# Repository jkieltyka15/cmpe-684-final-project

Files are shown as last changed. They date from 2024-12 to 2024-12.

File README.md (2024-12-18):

# Smart Wireless Sensor Network (WSN) Parking Lot
## Overview
This repository is a collection of research, hardware implementations and software implementations for a smart parking lot that displays the vacancy status of each parking space. The scope of the project was limitted to ten spaces and is meant to be a proof of concept to satisfy the final project requirement for CMPE-684: Wireless Sensor Networks at the University of Maryland, Baltimore County.

## Hardware
All PCB design files were created using KiCad and all stl files for 3D prints were developed using Autodesk TinyCAD. The filament used for the 3D prints is PLA.

For electronics, the project truly revolves around the Arduino Nano. All of the sensor nodes and the base station utilize this microcontroller. Time of Flight (ToF) sensors are used to detect if a vehicle is present and the NRF24L01 radio is used for network communication between sensor nodes and the base station.

The output of the base station is composite video with a limitted display resolution. However, the final resolution seems to scale well with most display scalers.

## Software
The Arduino IDE was used for the research examples. However, PlatformIO was used for the actual implementation since it offered superior project structure and organization.

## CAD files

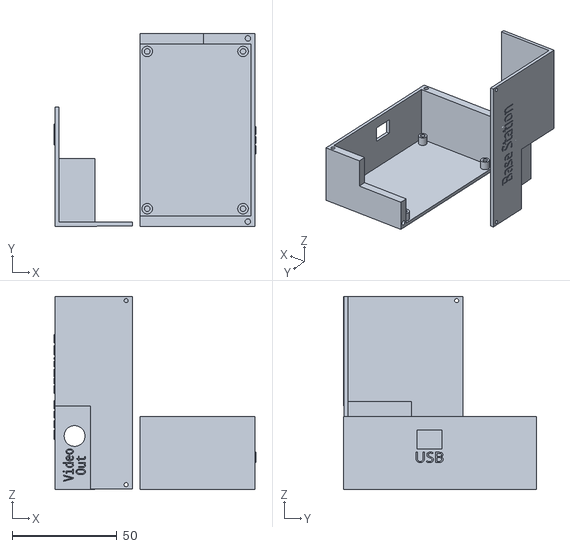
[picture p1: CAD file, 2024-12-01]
base_station/3d_print/base_station.stl
96.5 x 92.3 x 92.3

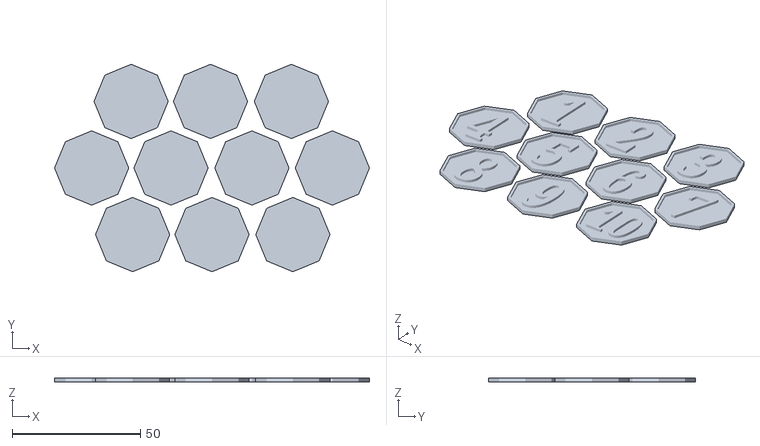
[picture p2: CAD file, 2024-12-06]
sensor_node/3d_print/number_tags.stl
123.0 x 81.0 x 1.50

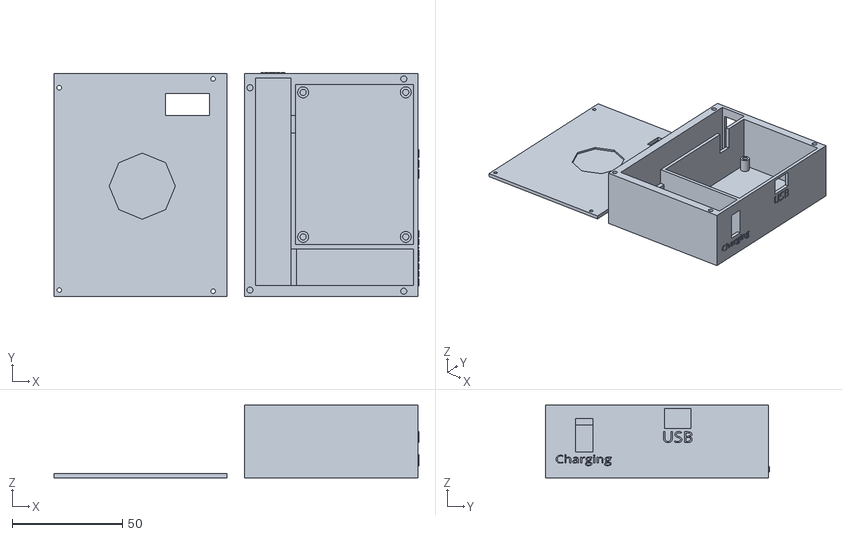
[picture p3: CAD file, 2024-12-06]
sensor_node/3d_print/sensor_node.stl
165.4 x 101.5 x 33.0

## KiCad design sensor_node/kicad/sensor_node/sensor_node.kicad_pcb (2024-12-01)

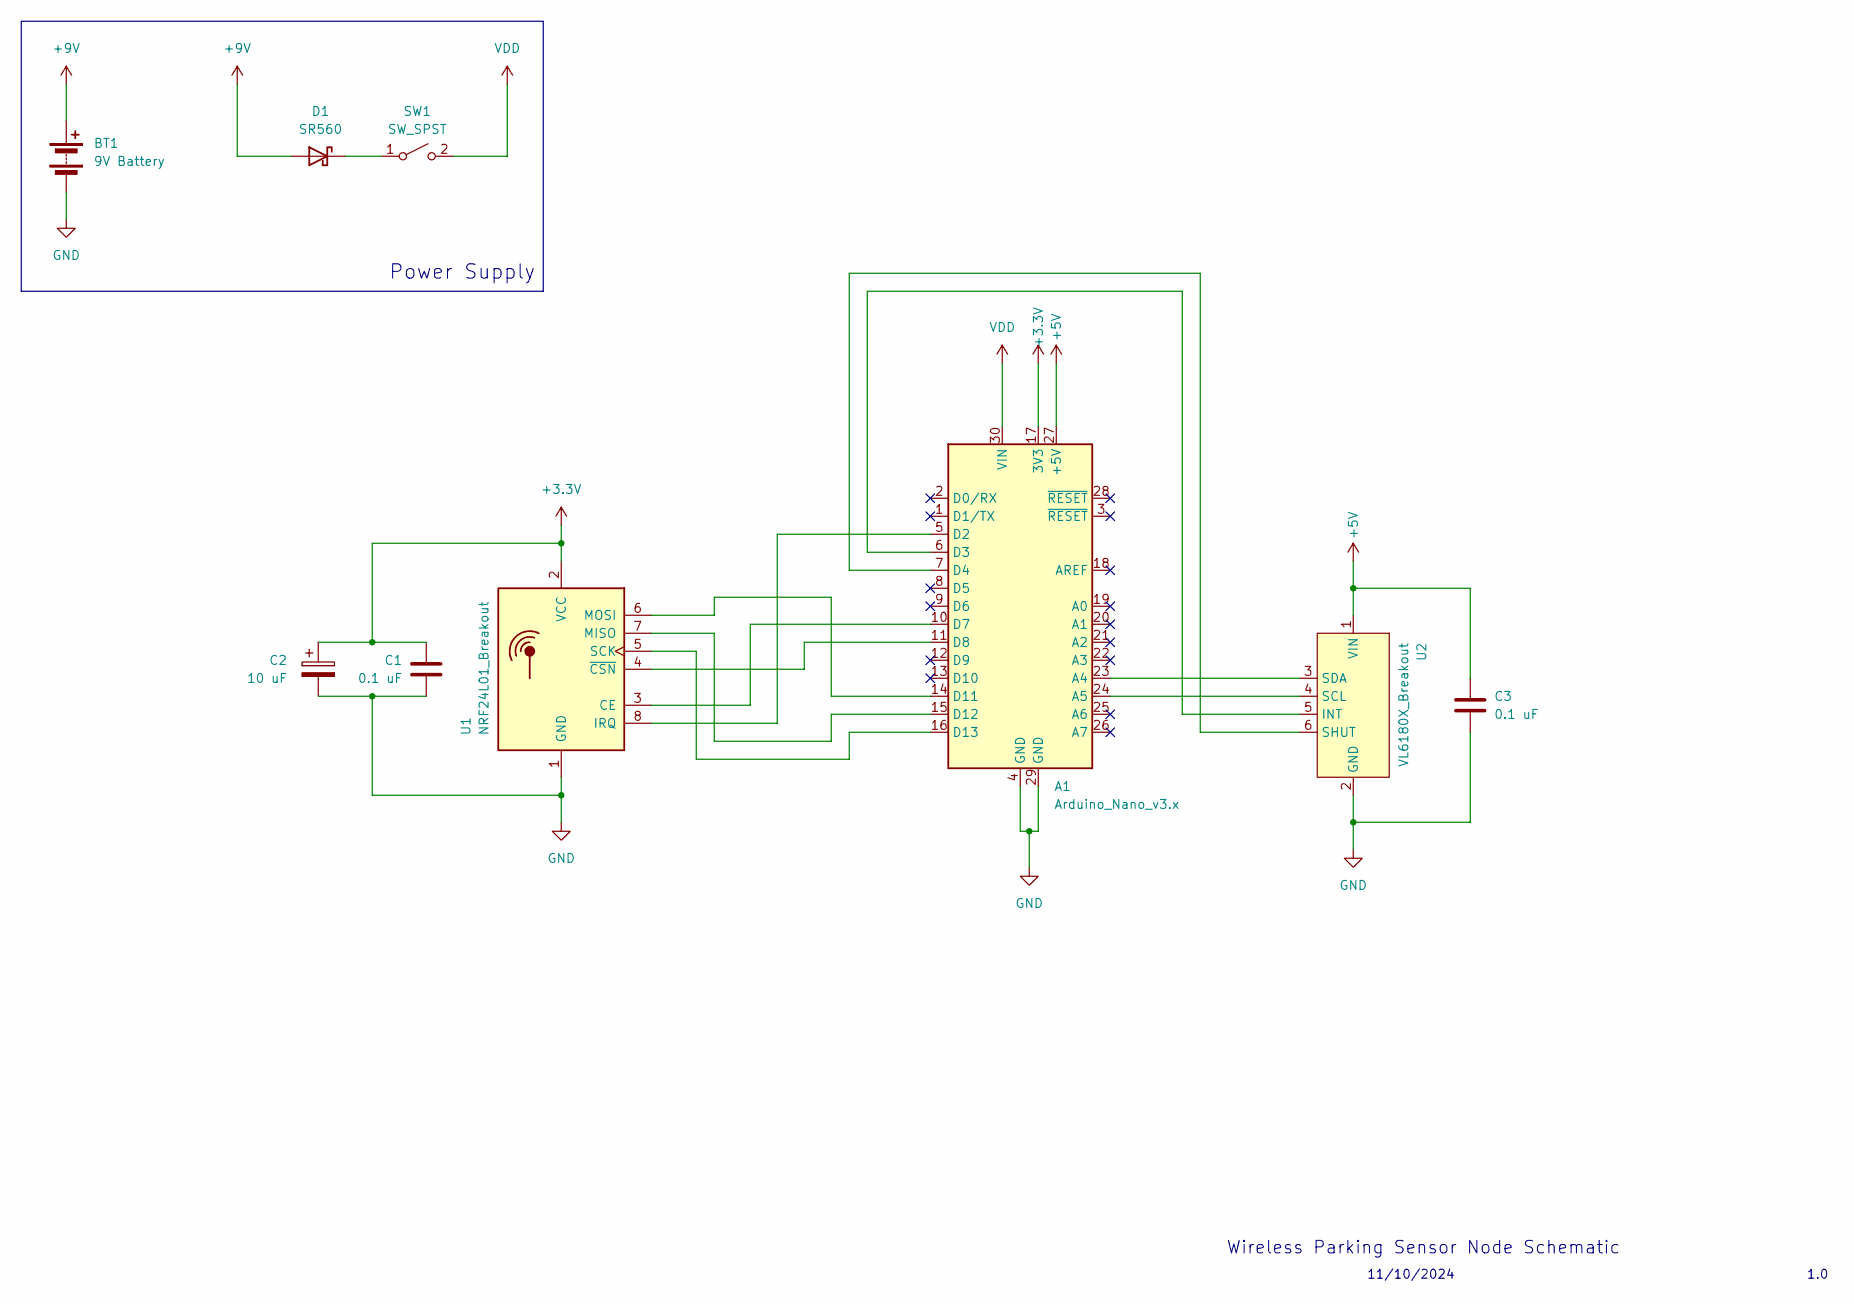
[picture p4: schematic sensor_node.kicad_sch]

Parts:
A1: Arduino_Nano_v3.x; Arduino_Nano
BT1: 9V Battery; PinHeader_1x02_P2.54mm_Vertical
C1, C3: 0.1 uF; C_Disc_D5.1mm_W3.2mm_P5.00mm
C2: 10 uF; CP_Radial_D5.0mm_P2.50mm
D1: SR560; D_DO-201AD_P15.24mm_Horizontal
SW1: SW_SPST; PinHeader_1x02_P2.54mm_Vertical
U1: NRF24L01_Breakout; nRF24L01_Breakout
U2: VL6180X_Breakout

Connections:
+3.3V: A1.17 (3V3), C1.1, C2.1, U1.2 (VCC)
+5V: A1.27 (+5V), C3.1, U2.1 (VIN)
+9V: BT1.1 (+), D1.2 (A)
GND: A1.4 (GND), A1.29 (GND), BT1.2 (-), C1.2, C2.2, C3.2, U1.1 (GND), U2.2 (GND)
unnamed: A1.23 (A4), U2.3 (SDA)
unnamed: A1.24 (A5), U2.4 (SCL)
unnamed: A1.5 (D2), U1.8 (IRQ)
unnamed: A1.6 (D3), U2.5 (INT)
unnamed: A1.7 (D4), U2.6 (SHUT)
unnamed: A1.10 (D7), U1.3 (CE)
unnamed: A1.11 (D8), U1.4 (~CSN)
unnamed: A1.14 (D11), U1.6 (MOSI)
unnamed: A1.15 (D12), U1.7 (MISO)
unnamed: A1.16 (D13), U1.5 (SCK)
unnamed: D1.1 (K), SW1.1 (A)
VDD: A1.30 (VIN), SW1.2 (B)

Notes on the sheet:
11/10/2024
1.0
Wireless Parking Sensor Node Schematic
Power Supply

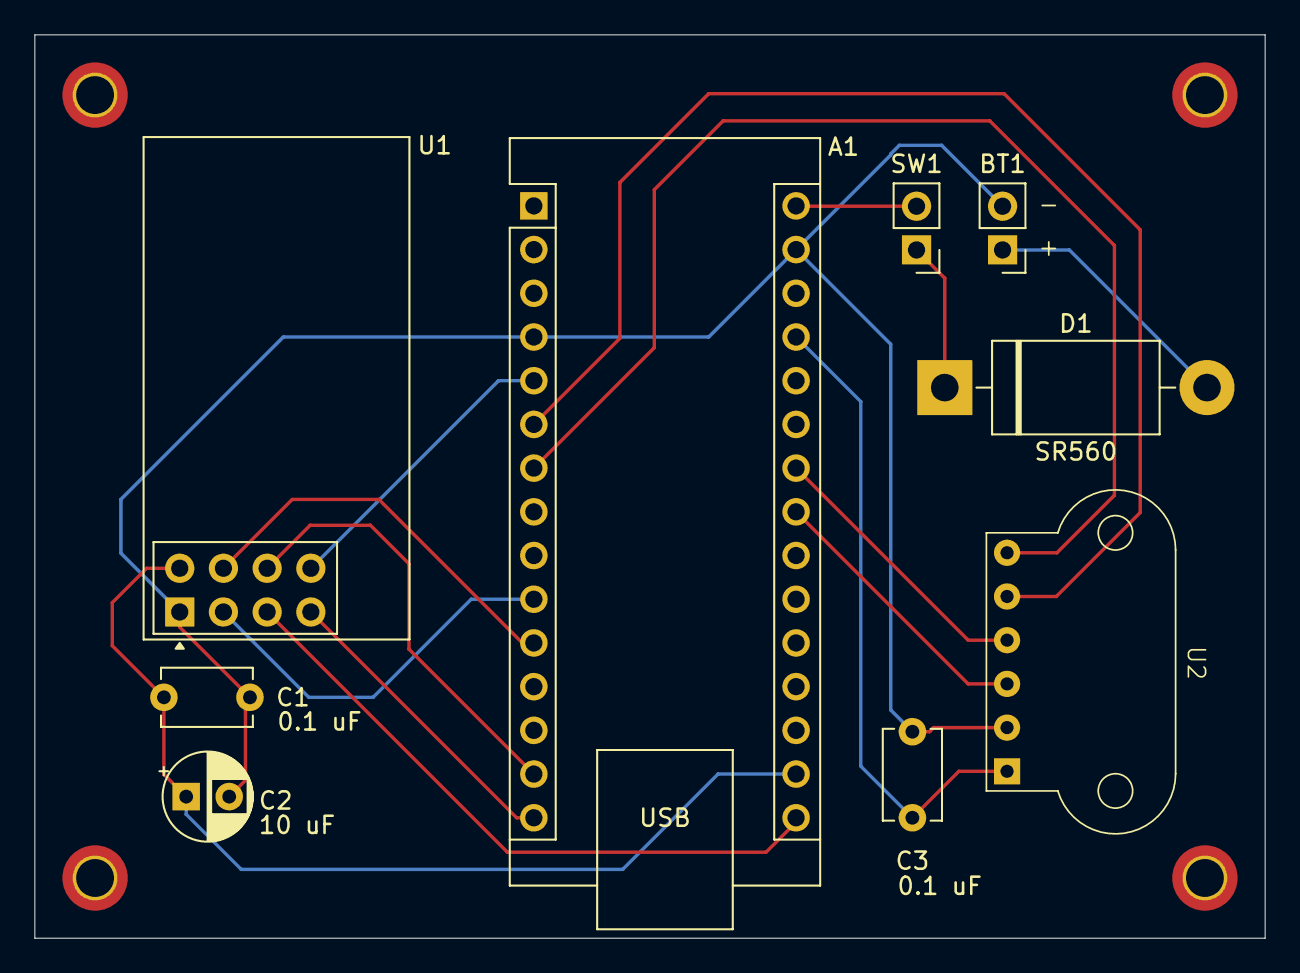
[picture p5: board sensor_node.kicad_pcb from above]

Board: 2 copper layers, 71.5 x 52.5 mm, 13 parts (0 on the bottom side), 16 nets.

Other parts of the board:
MH1, MH2, MH3, MH4: MountingHole_2.2mm_M2_DIN965_Pad_TopBottom

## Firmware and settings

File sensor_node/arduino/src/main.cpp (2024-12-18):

/**
* @brief: Contains the main run loop for the parking sensor node.
* @file: main.cpp
*
* @author: jkieltyka15
*/

// standard libraries
#include <Arduino.h>
#include <stdlib.h>
#include <Wire.h>
#include <Adafruit_VL6180X.h>

// local libraries
#include <Log.h>

// local dependencies
#include "sensornode.hpp"
#include "parkingmap.hpp"


// unique ID for node
#define NODE_ID 10

// baud rate for serial connection
#define SERIAL_BAUD 9600


#define MAIN_LOOP_DELAY_MIN_MS 75   // minimum delay in main loop in milliseconds
#define MAIN_LOOP_DELAY_MAX_MS 150  // maximum delay in main loop in milliseconds

// number of loop iterations without transmitting a message
// before sending out a heartbeat
#define LOOPS_BEFORE_HEARTBEAT 25

// size of message buffer
#define MSG_BUFFER_SIZE 32


// parking sensor node
SensorNode node = SensorNode(NODE_ID);

// counter for tracking loop iterations since the last
// message was transmitted
uint8_t loops_since_last_transmission = 0;

/**
 * @brief Initialize all necessary objects and variables.
 */
void setup() {

    Serial.begin(SERIAL_BAUD);
  
    // initialize the sensor node
    if (false == node.init()) {

        ERROR("Failed to initialize sensor node. Check hardware")

        // hang since failure is not recoverable
        while(1);
    }

    INFO("setup complete")
}


/**
 * @brief Main program run loop.
 * 
 * Continuously monitors the status of a parking space and sends a message if
 * it changes or the status is requested. Additionally, relays messages from
 * other nodes.
 */
void loop() {

    // track iterations since last transmission
    loops_since_last_transmission++;

    // determine if parking space status has changed or time for heartbeat
    if ((true == node.is_sensor_status_changed())
        || LOOPS_BEFORE_HEARTBEAT <= loops_since_last_transmission) {

        // determine recepient
        int16_t rx_id = get_next_ingress_node(node.get_id());

        // no recepient available
        if (0 > rx_id) {
            WARN("Nobody to send update to")
        }

        else {
            // transmit update
            if (false == node.transmit_update((uint8_t)rx_id)) {
                ERROR("Failed to transmit update message to Node " + rx_id)
            }

            // heartbeat message successfully sent
            else if (LOOPS_BEFORE_HEARTBEAT <= loops_since_last_transmission) {
                INFO("heartbeat update message sent to Node " + + rx_id)
            }

            // update message successfully sent
            else {
                INFO("update message sent to Node " + + rx_id)
            }

            // reset heartbeat iteration counter
            loops_since_last_transmission = 0;
        }
    }

    // check if a message has been received
    else if(true == node.is_message()) {

        uint8_t buffer[MSG_BUFFER_SIZE];
        memset(buffer, 0, sizeof(buffer));

        if (false == node.read_message((uint8_t**)(&buffer), (uint8_t)sizeof(buffer))) {
            ERROR("Failed to read message");
        }

        else {
            // convert buffer to Message
            Message msg = Message();
            memcpy(&msg, buffer, sizeof(msg));

            // verify message is for node
            if (node.get_id() != msg.get_rx_id()) {
                WARN("Message intended for Node " + msg.get_rx_id() + " not Node " + node.get_id());
            }

            // react accordingly based on message type
            else {

                uint8_t type = msg.get_type();
                switch(type) {

                    case MESSAGE_UPDATE: {

                        INFO("Received UPDATE message from Node " + msg.get_tx_id())
                        
                        // convert buffer to UpdateMessage
                        UpdateMessage update_msg = UpdateMessage();
                        memcpy(&update_msg, buffer, sizeof(update_msg));

                        // determine recepient
                        int16_t rx_id = get_next_ingress_node(node.get_id());

                        // no recepient available
                        if (0 > rx_id) {
                            WARN("Nobody to send update to")
                        }

                        else {
                            // create new message to forward
                            uint8_t tx_id = node.get_id();
                            uint8_t node_id = update_msg.get_node_id();
                            bool is_vacant = update_msg.get_is_vacant();
                            UpdateMessage new_msg = UpdateMessage(rx_id, tx_id, node_id, is_vacant);

                            // forward the message
                            if (false == node.transmit_update(&new_msg)) {
                                ERROR("Failed to transmit update message to " + rx_id)
                            }

                            // reset heartbeat iteration counter
                            loops_since_last_transmission = 0;
                        }

                        break;
                    }

                    default:
                        WARN("Unknown message type received")
                        break;
                }
            }
        }
    }

    // nothing to do
    else {
        delay(random(MAIN_LOOP_DELAY_MIN_MS, MAIN_LOOP_DELAY_MAX_MS));
    }
}

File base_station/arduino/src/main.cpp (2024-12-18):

/**
* @brief: Contains the main run loop for the parking lot base station.
* @file: main.cpp
*
* @author: jkieltyka15
*/

// standard libraries
#include <Arduino.h>
#include <stdlib.h>
#include <Wire.h>

// local libraries
#include <Log.h>

// local dependencies
#include "basestation.hpp"
#include "parkingdisplay.hpp"


// unique ID for base station
#define BASE_STATION 0

// baud rate for serial connection
#define SERIAL_BAUD 9600

// delay in main loop in milliseconds
#define MAIN_LOOP_DELAY_MS 100

// size of message buffer
#define MSG_BUFFER_SIZE 32


// base station of WSN
BaseStation base_station = BaseStation(BASE_STATION);


/**
 * @brief Initialize all necessary objects and variables.
 */
void setup() {

    Serial.begin(SERIAL_BAUD);
  
    // initialize the base station
    if (false == base_station.init()) {

        ERROR("Failed to initialize base station. Check hardware")

        // hang since failure is not recoverable
        while(1);
    }

    // intialize the screen
    if (false == init_parking_display()) {

        ERROR("Failed to initialize screen. Check hardware")

        // hang since failure is not recoverable
        while(1);
    }

    // update screen to show the parking map
    draw_parking_map();

    INFO("setup complete")
}


/**
 * @brief Main program run loop.
 * 
 * Continuously listens for messages from sensor nodes and updates
 * the parking space status accordingly on a display.
 */
void loop() {

    if(true == base_station.is_message()) {

        uint8_t buffer[MSG_BUFFER_SIZE];
        memset(buffer, 0, sizeof(buffer));

        if (false == base_station.read_message((uint8_t**)(&buffer), (uint8_t)sizeof(buffer))) {
            ERROR("Failed to read message");
        }

        else {
            // convert buffer to Message
            Message msg = Message();
            memcpy(&msg, buffer, sizeof(msg));

            // verify message is for base station
            if (base_station.get_id() != msg.get_rx_id()) {
                WARN("Messaged intended for Node " + msg.get_rx_id() + " not Node " + base_station.get_id());
            }

            // verify sender has a valid ID
            else if(false == base_station.is_valid_sensor_node(msg.get_tx_id())) {
                WARN("Message was from invalid Node " + msg.get_tx_id());
            }

            // react accordingly based on message type
            else {

                uint8_t type = msg.get_type();
                switch(type) {

                    case MESSAGE_UPDATE: {

                        INFO("Received UPDATE message from Node " + msg.get_tx_id())
                        
                        // convert buffer to UpdateMessage
                        UpdateMessage update_msg = UpdateMessage();
                        memcpy(&update_msg, buffer, sizeof(update_msg));

                        uint8_t node_id = update_msg.get_node_id();
                        bool is_vacant = update_msg.get_is_vacant();

                        // verify node to update has a valid ID
                        if(false == base_station.is_valid_sensor_node(node_id)) {
                            WARN("Cannot update status of invalid Node " + node_id);
                        }

                        // only update if vacancy status changed
                        else if (is_vacant != base_station.get_node_status(node_id)) {

                            // update the status of the reporting node
                            (void) base_station.update_node_status(node_id, is_vacant);
                            
                            // node status is vacant
                            if (true == is_vacant) {
                                INFO("Node " + node_id + " is now vacant")
                            }

                            // node status is occupied
                            else {
                                INFO("Node " + node_id + " is now occupied")
                            }

                            // update the status of the parking space
                            update_parking_space(node_id, is_vacant);
                        }

                        break;
                    }

                    default:
                        WARN("Unknown message type received")
                        break;
                }
            }
        }
    }

    // nothing to do
    else {
        delay(MAIN_LOOP_DELAY_MS);
    }
}

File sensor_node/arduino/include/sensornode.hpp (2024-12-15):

/**
* @brief: Contains the prototype of the SensorNode class.
* @file: sensornode.hpp
*
* @author: jkieltyka15
*/

#ifndef _SENSOR_NODE_HPP_
#define _SENSOR_NODE_HPP_

// standard libraries
#include <Arduino.h>
#include <Wire.h>
#include <Adafruit_VL6180X.h>
#include <nRF24L01.h>
#include <RF24.h>

// local libraries
#include <Message.h>


#define RF24_CE_PIN 7   // NRF24L01 CE pin assignment
#define RF24_CSN_PIN 8  // NRF24L01 CSN pin assignment

// width in bytes of the radio's address
#define RF24_ADDRESS_WIDTH 4 


// different states of the ToF sensor
enum tof_sensor_status_t {
    NOT_INITIALIZED = 0,
    VACANT = 1,
    OCCUPIED = 2
};


class SensorNode {

    private:

        // unique id of the sensor node
        uint8_t node_id = 0;

        // most recently read status of the sensor
        tof_sensor_status_t sensor_status = NOT_INITIALIZED;

        // VL6180X ToF sensor
        Adafruit_VL6180X sensor = Adafruit_VL6180X();

        // NRF24L01 transciever radio
        RF24 radio = RF24(RF24_CE_PIN, RF24_CSN_PIN);
        uint32_t radio_address = 0;
        uint8_t radio_channel = 0;

        /**
         * @brief Calculates a given sensor node's radio address based on the node ID
         * 
         * @param node_id: ID of node to calculate address for
         * @return The calculated radio address for the node
         */
        uint32_t calculate_radio_address(uint8_t node_id);

        /**
         * @brief Calculates a given sensor node's radio channel based on the node ID
         * 
         * @param node_id: ID of node to calculate channel for
         * @return The calculated radio channel for the node (0-125)
         */
        uint8_t calculate_radio_channel(uint8_t node_id);


    public:

        /**
         * @brief Constructs a SensorNode object
         */
        SensorNode(uint8_t node_id);

        /**
         * @brief Initializes all variables and objects
         * 
         * Initializes all variables and objects for a SensorNode
         * object including the ToF sensor and transciever.
         * 
         * @return true on success. Otherwise false
         */
        bool init();

        /**
         * @brief Gets the most recently read ToF sensor status
         * 
         * @return Most recently read ToF sensor status
         */
        tof_sensor_status_t get_sensor_status();

        /**
         * @brief Determines if the last read sensor value differs from the current
         * 
         * Determines if the last read sensor value differs from the current. If a
         * sensor error occurs, false will be returned regardless of the prevous
         * sensor status.
         * 
         * @return If the ToF sensor status has changed since it was last read
         */
        bool is_sensor_status_changed();

        /**
         * @brief Transmit update to sensor node or base station.
         * 
         * @param msg: Update message to be transmitted
         * @return True if successfully sent. Otherwise false
         */
        bool transmit_update(UpdateMessage* msg);

        /**
         * @brief Transmit update to sensor node or base station.
         * 
         * @param rx_node_id: ID of receiving node
         * @return True if successfully sent. Otherwise false
         */
        bool transmit_update(uint8_t rx_node_id);

        /**
         * @brief Determine if there is a message available to read
         * 
         * @return True if a message is available. Otherwise false
         */
        bool is_message();

        /**
         * @brief Gets a message from the message queue
         * 
         * @param buffer: buffer to hold message
         * @param size: size of buffer
         * @return Number of bytes read
         */
        bool read_message(uint8_t** buffer, uint8_t size);

        /**
         * @brief Get the ID of the node
         * 
         * @return ID of the node
         */
        uint8_t get_id();
};

#endif /* _SENSOR_NODE_HPP_ */

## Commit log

2024-11-10 Added a transmitter and receiver demo to confirm functionality of the nRF24L01 module with Arduino Nanos.
2024-11-12 Added a demo for the nRF24L01 to confirm functionality with an Arduino Nano.
2024-12-01 Added KiCad project files for the base station and sensor node. Added stl for base station's 3d printed enclosure. Added .gitignore.
    [base_station.kicad_pcb, base_station.kicad_sch, base_station.stl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]
2024-12-06 Added stl files for the sensor node enclosure and number tags.
    [number_tags.stl, sensor_node.stl]
2024-12-14 Added PlatformIO project for the sensor node. Began implementing SensorNode class. Implemented parking space detection for sensor node.
2024-12-15 Implemented transmitting and forwarding update messages. Currently received message data is not what is expected.
2024-12-15 Resolved issue with messages not being sent and received correctly. Added auto ACK and dynamic payload size.
    [main.cpp, sensornode.hpp]
2024-12-15 Added ingress routing to base station for sensor nodes via a parking map algorithm.
2024-12-15 Fixed grammar in logs.
    [main.cpp]
2024-12-16 Base station now saves reported statuses of sensor nodes.
2024-12-17 Fixed auto ack feature. Added persistent message attempts when messages fail to be delivered.
    [main.cpp]
2024-12-17 Removed persistent messaging. Causes network traffic jams.
    [main.cpp]
2024-12-17 Sensor nodes wait for channel to not have traffic before sending a message.
2024-12-17 Added heartbeating and variable loop delay to avoid collision.
    [main.cpp]
